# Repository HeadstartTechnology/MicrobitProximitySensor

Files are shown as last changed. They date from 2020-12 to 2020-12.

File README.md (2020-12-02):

# MicrobitProximitySensor
Code and files for the Microbit Proximity Sensor board 

The motivation for this project was to provide a fun and easy to use social distancing tool, for use in any environment where people need to gather but still need to maintain proper distancing (such as gyms, schools, offices, etc). The system works by sending out radio bursts at regular intervals using the built-in Bluetooth radio, and sounding an alarm if it detects the signal strength from another Microbit as being below a preset value (which is indicative of distance between the devices).

Microbits can be configured to use separate radio channels, so it is possible to configure 'bubbles' where individual Microbits only react to Microbits from a different bubble. Example code for these configurations will be uploaded shortly.

The Microbit is ideally suited as for this project as it incorporates all required sensors in an affordable and flexible package. The PCB in this project adds a buzzer for sound and batteries for power. Both V1 and V2 are supported.

Please see WIKI for code pictures or download hex files for makecode editor. 

The required electronic components and mechanical parts to build the Proximity Monitoring Board
 
| Component |  PCB ID |  Kitronik Stock Code | Quantity |
| --- | :---: | :---: | :---: |
| Printed Circuit Board | | 56108 | 1 |
| AA Battery Holder | BH1, BH2 | 2263 | 2 |
| Piezo Buzzer | BZ1 | 3308 | 1 |
| JST Wire | CN2 | 4159 | 1 |		
| Slide Switch | SW1 | 3422 | 1 |
| M3 x 12mm Bolt | | 2314 | 2 |
| M3 nut | | 2315 | 2 |
| 6mm M3 nylon Spacer | | 2335 | 2 |

Parts can be ordered from [Kitronik.co.uk](https://www.kitronik.co.uk)

A big Thank You to Phil, Kevin and the entire team at Kitronik for supporting this project!

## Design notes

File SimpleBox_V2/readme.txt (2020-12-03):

Cad Designs and STL for Simple Box V2

Design files can be opened with DesignSpark Mechanical - free and easy to use. Adapt as required

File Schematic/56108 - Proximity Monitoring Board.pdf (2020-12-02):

S/C: 56108

Drawn By: Phil Bradwell | Proximity Monitoring Board
Version: V1.0 | 15/10/2020 10:35
| | Sheet: 1/1

CIRCUIT NOTES
---------------------- CN1 pad connections are screw holes pads for P0 and GND of the BBC micro:bit.

CN2 is two pads to solder JST wire to the board.
This wire then plugs into the JST connector on the top of the BBC micro:bit
The connector is molded for polarity. Connections are labelled on the PCB
The power supply to the micro:bit can then work down to 2.0V allowing the use for rechargable batteries (nominal voltage 1.2V per cell)

Current consumption is based on 50mA (inc BBC micro:bit)
Typical Batter capacity is 1500mAh
Battery life to be 1500m/50m = 30 hours
GND | GND

2way

P$1 P$1 P$2 P$2

BZ1 P$1 P$1 P$2 P$2 P$3 P$3

SW1

BH1

BH2

1

2CN2
P0 | P0
0V | GND CN1

+VBATT
+ | BH311-1P
+ | BH311-1P

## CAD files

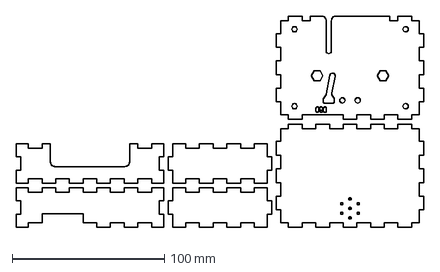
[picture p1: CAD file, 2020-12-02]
CAD/Basic Box Case.dxf
268.0 x 142.0 mm

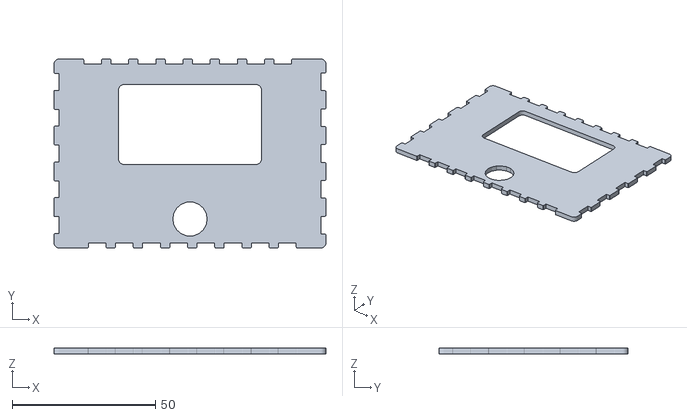
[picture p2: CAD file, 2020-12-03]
SimpleBox_V2/revised_box_lid_V2.stl
95.0 x 66.0 x 2.00

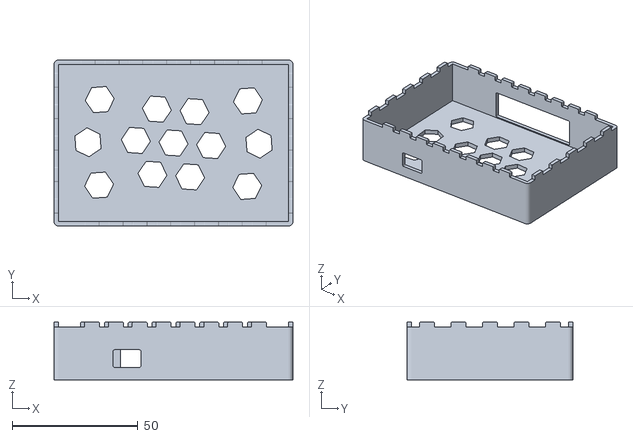
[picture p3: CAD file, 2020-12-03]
SimpleBox_V2/revisedbox_v2.stl
95.0 x 66.0 x 23.0

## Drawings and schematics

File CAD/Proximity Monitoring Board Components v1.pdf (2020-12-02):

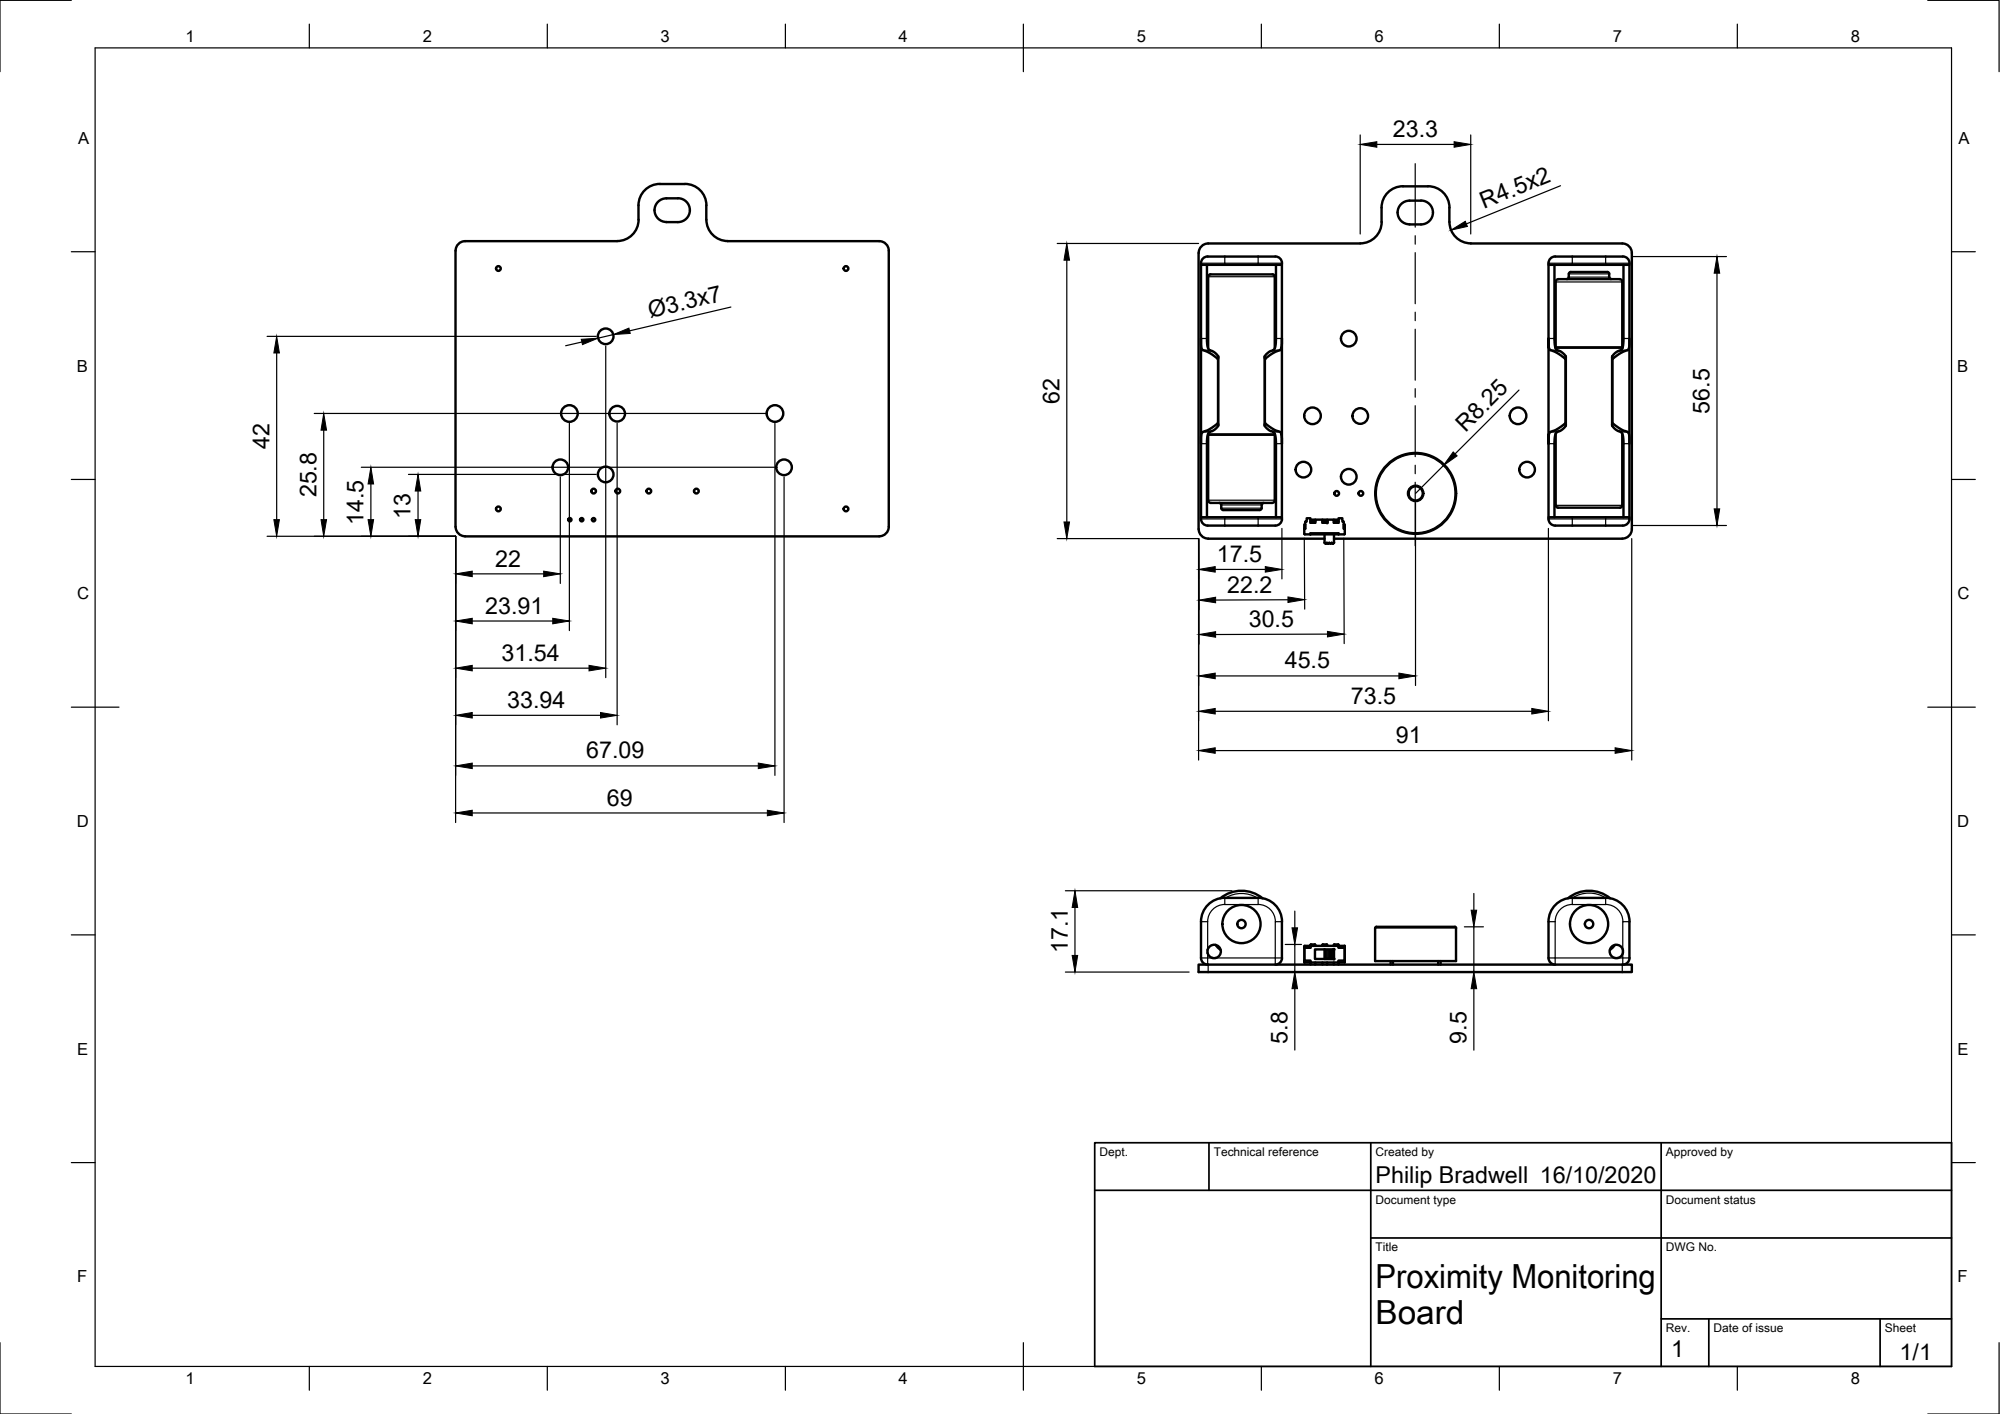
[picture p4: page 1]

Dept. | Technical reference | Created by Philip Bradwell 16/10/2020 | Approved by

Document type | Document status

Title Proximity Monitoring Board | DWG No.

Rev. | Date of issue | Sheet 1/1
